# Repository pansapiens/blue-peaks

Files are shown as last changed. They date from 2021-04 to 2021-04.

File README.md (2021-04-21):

# Blue Peaks

A low-cost remix of [Mutable instrument's Peaks](https://mutable-instruments.net/modules/peaks/) and [Matias Levy Alfie's $peaks](https://github.com/matias-levy/peaks).

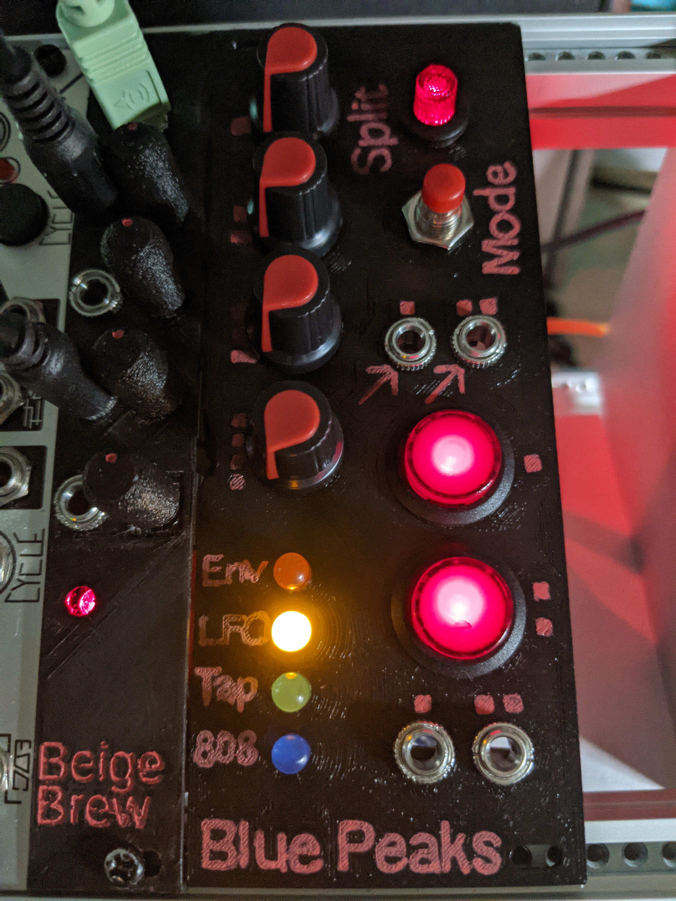
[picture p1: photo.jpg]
Photo of the finished build


## Description
This is a 'skiff friendly' remix of Matias Levy Alfie's awesome [$peaks](https://github.com/matias-levy/peaks) module (which in turn is based on [Mutable instrument's Peaks](https://mutable-instruments.net/modules/peaks/)), with the PCB redesigned with a depth of 50 cm. See [Matias repo](https://github.com/matias-levy/peaks) for details on how he redesigned the module to use a Blue Pill without an external DAC !

It also includes versions of the original Peaks and the Dead Man's Catch firmwares trimmed to fit on a Blue Pill (STM32F103C8T6 dev board) with only 64k of flash. You can use this firmware with Matias' $peaks if you prefer to make that PCB.

Like Matias' original remix, the project is designed to use a single sided home-etched PCB with ~~a couple of~~ far too many jumper wires.
## Firmwares
There's the option to flash one of two firmwares that where ported. The original Mutable Instruments one is in the `firmware/peaks` directory. The [Mutated Mutables Dead Man's Catch](https://github.com/timchurches/Mutated-Mutables/tree/master/peaks) is in the `firmware/peaks2`.

By default the "Number Station" Easter egg in the firmware is disabled to allow it to fit on a Blue Pill with 64k of flash. If you have 128k of flash it can be enabled in the `makefile` (see below).

Compiled binaries and HEX files are provided for both under `firmware/build`.

## Matias changes from Peaks
* Added a driver for the PWM DAC running at **14 bit depth, 48Khz sampling rate.** (File in firmware/peaks/drivers/pwm_dac.h)
* Activated the clock for the TIM4 in firmware/peaks/drivers/system.cc
* **Bypassed the bootloader:** This was done as to simplify the code, it does not interfere with the calibration functionality of the module.
* Redesigned the output portion of the hardware to accommodate to the PWM levels.

## Further changes from $peaks
* Modified board layout to be 'skiff friendly' (PCB is 50mm deep, 110 mm high)
* Disabled the "Number Station" Easter egg by default, to fit in 64k flash.
* Tweaked to use default KiCad footprints, less vertically mounted resistors, use 9mm horizontal Alpha-style pots (eg RD901F / RK09)
* Use 5.1V Zener diodes rather than 3.6V.
* Tweaked tracks to work better for my own PCB production method (pen plotter + etching)

## Build guide

Mine looked like this. You are on your own ... have fun !

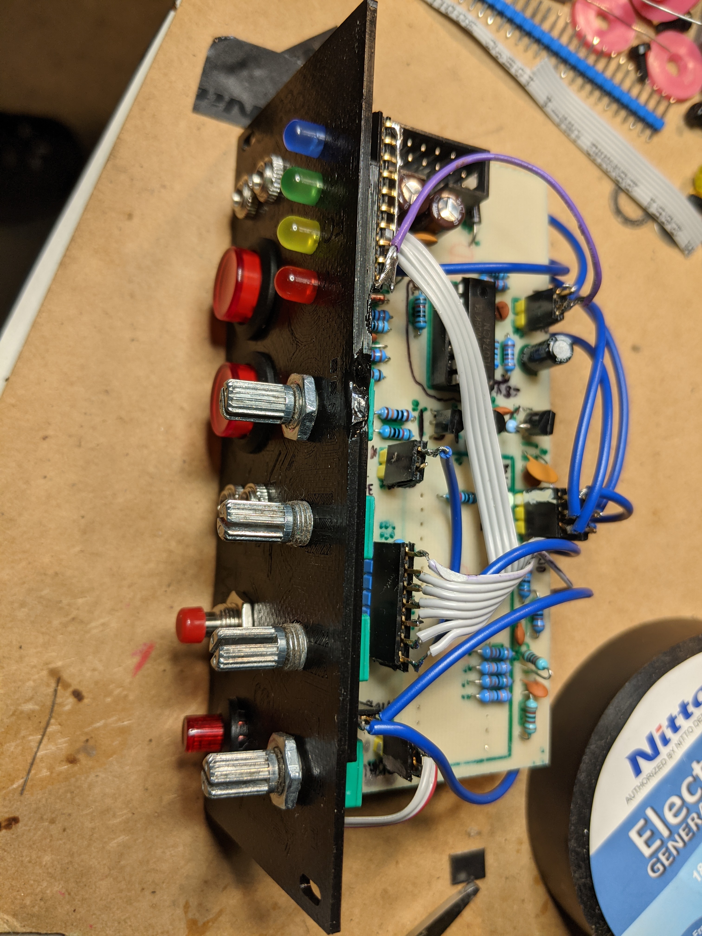
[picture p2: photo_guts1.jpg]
PCB 'front'


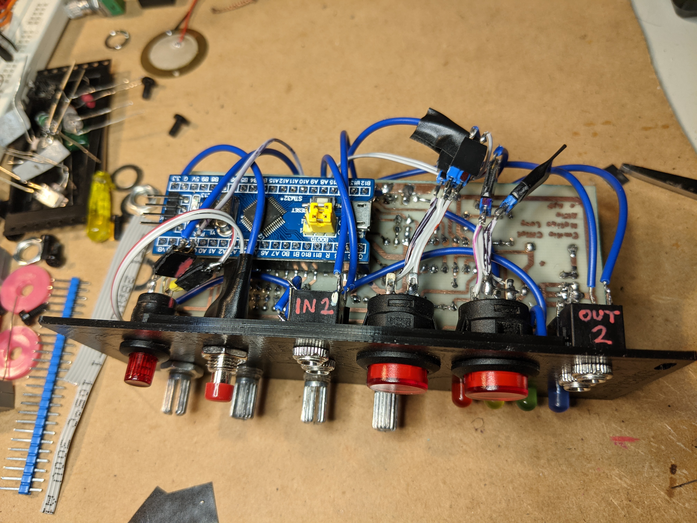
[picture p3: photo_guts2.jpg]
PCB 'back'


Yup, it's a rat's nest. I would love to find the time to redesign further to limit the number of jumper wires.

**WARNING WARNING WARNING** - I found some weirdness in the orientation / side of PCB that some components needed to be soldered in this design. By the time I discovered it I'd already made the PCBs so I worked around it. I ended up soldering the Blue Pill on the opposite side to the other components (awkward), and flipping the transistors, voltage regulator, TL074 and power socket 180 degrees to ensure the pinouts correctly aligned with the approriate tracks / schematic. So fair warning - be paranoid about component orientation and don't blindly trust the silkscreen layer. Visually check that the pins you are soldering make sense with the tracks they connect to (eg wide ground trace). If you don't check carefully as you go, you'd better enjoy desoldering components ....

## Flashing and development
Build with:
```
cd firmware
make -f peaks/makefile
make -f peaks/makefile bin
```

You'll need Python 2.x and `numpy`, as well as a typical Linux build environment for ARM cross-compilation 
(eg On Ubuntu 20.04, do `sudo apt install gcc-arm* build-essential` and set `TOOLCHAIN_PATH = /usr/` in `firmware/peaks/makefile`).

If you happen to have a Blue Pill with 128k of flash, you can enable the "Number Station" Easter egg by uncommenting the `NUMBER_STATION` variable in `firmware/peaks/makefile`.

To make it easier there are pre-compiled binaries and .HEX files in `firmware/build`, this can be flashed directly to the bluepill using [STM32CubeProgrammer](https://www.st.com/en/development-tools/stm32cubeprog.html).

Another option is to install the [mutable-dev-environment](https://github.com/pichenettes/mutable-dev-environment) and replace the peaks folder with the one inside /firmware, then executing

    make -f peaks/makefile upload_serial

We use this command because the bootloader is bypassed.

## Thanks
Many thanks Emilie Gillet for open-sourcing her work which is a constant inspiration for many musicians and makers, and encourage everyone interested in this project to checkout the [Mutable instrument's Forum](https://forum.mutable-instruments.net/) in which Emilie is a very active member.

## TODO, IDEAS

- Resolve issues with flipped components / which side to solder / front vs. back traces.
  - To get correct connections I needed to solder the Blue Pill pin header sockets on the 'wrong' side of the PCB 
    (the opposite side to other components - quite awkward on a single sided PCB),
    and rotate the TL074, transistors and voltage regulator 180 degrees to allow them to be correctly soldered to 
    the 'right' side of the board.
    
- Change some GPIOs in the firmware to make PCB layout easier/cleaner.
- Use a 3.3V supply to power the Blue Pill (eg via LD1117AV33 / LM1117-3.3) rather than 5V - apparently the 5V to 3.3V regulator on Blue Pill boards can't handle more the 100mA, so it's safer to supply 3.3V directly.
- For matching R14/R16 to the Zener reference voltage, 21k and 14k resistors are tricky to find. Either use a 20+1k / 13+1k (or maybe use a resistor + 1k or 2k trimpot to allow manual calibration ?)
- Create a two PCB design with pots/jacks/switches soldered on front board. The single board version is a mess of wires.
- Add CV control for each of the four pots !

While I don't plan to tackle any of these changes within the foreable future, I figured it was worth documenting.

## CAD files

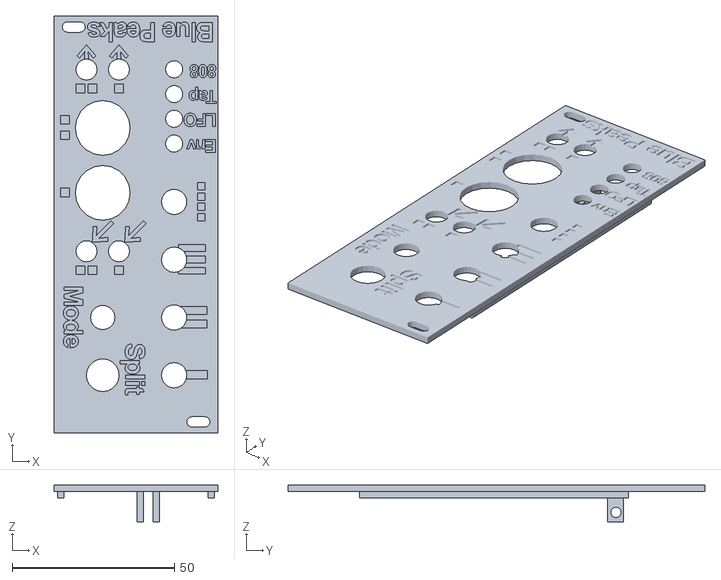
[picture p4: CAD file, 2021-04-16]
frontpanel/stl/EurorackPanel_10HP_Blue_Peaks.stl
50.5 x 128.5 x 11.3

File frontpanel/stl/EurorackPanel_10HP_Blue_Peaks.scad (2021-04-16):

// In this design, the illuminated buttons are inserted from the front of the panel and are held without nuts.
// This means the fit of the holes needs to be fairly snug. If you have different illuminated momentary buttons
// you'll need to tweak the radii in ledMomRad, bbRadius and momRad.

// Large momentary trigger buttons are Shin Chin (SCI) R13-523A (R13-523A-05-BR, Mouser code: 112-R13-523A-05-BR).
// Split/twin momentary button is Shin Chin (SCI) R13-548A (R13-548AL-05-BRR, Mouser code: 112-R13-548AL-BRR)

// Mode toggle momentary button has a ~6mm diameter metal thread with nut (similar to Philips PBS-110, or maybe Shin Chin R13-24A).
// LEDs are standard 5mm diameter LEDs.
// Sockets are standard threaded 3.5mm mono jacks with nuts.
// Pots are Alps-style (RK09) metal threaded with nuts.

// TODO: Mounting bracket for M3 screw is too weak, needs be thicker at the base where it joins the panel

$fn = 24;

panelThickness = 2;
panelHp = 10;  // 10HP is actually 50.50 based on http://www.doepfer.de/a100_man/a100m_e.htm
holeCount = 2;
holeWidth = 7.08; //If you want wider holes for easier mounting. Otherwise set to any number lower than mountHoleDiameter. Can be passed in as parameter to eurorackPanel()

threeUHeight = 133.35; //overall 3u height
panelOuterHeight = 128.5;
panelInnerHeight = 110; //rail clearance = ~11.675mm, top and bottom
railHeight = (threeUHeight-panelOuterHeight)/2;
mountSurfaceHeight = (panelOuterHeight-panelInnerHeight-railHeight*2)/2;

// Start and end coordinates of PCB top/bottom edges
innerStartY = 0 + ((panelOuterHeight - panelInnerHeight)/2);
innerEndY = panelOuterHeight - ((panelOuterHeight - panelInnerHeight)/2);

echo("mountSurfaceHeight", mountSurfaceHeight);

hp=5.08;
// This is a 'naive' width - based on based on http://www.doepfer.de/a100_man/a100m_e.htm,
// Doepfer panel widths have some tolerances/rounding in values.
// 
// panelWidth=panelHp*hp;
panelWidth=50.50; // 10HP

// R13-548A
ledMomRad = (8.5 + 1.6)/2;  // snug + tolerance/slope (snap fit)   // (8.5 + 1)/2 too tight // (10+1)/2 far too loose // (8.5 + 2)/2 slightly loose
momRad = (6.5 + 1)/2;  // snug + tolerance, secured with nut      // good fit

// R13-523A - these are snap fit buttons, so we should get a snug fit even with a bit of slop
bbRadius=(15.5 + 1.4)/2; // snug + tolerance/slop  //(15.5 + 1)/2 too tight // (17.5+1)/2 far too loose  // (15.5 + 2)/2 a bit loose

// plastic 9mm Alpha-style RK09 vertical pots, snug fit, no nut
// potRadius==6.45/2;

// metal alpha pot (knurled) - loose fit for attaching with nut
potRadius=7.8/2;  // 7/2 too tight  // 8.2/2 a bit loose

potHoleSpacing=17.8;

// snug fit 3.5mm jack, secured with nut
socketRadius=6.5/2;  // good fit

ledHoleWidth = 5.3; // 5.3 tight fit, won't fall out // 5.1 too tight  // 5.5 fits but slightly loose

mountHoleDiameter = 3.2;
mountHoleRad = mountHoleDiameter/2;
hwCubeWidth = holeWidth-mountHoleDiameter;
mountholeXOffset=1;

offsetToMountHoleCenterY = mountSurfaceHeight/2;
offsetToMountHoleCenterX = hp - hwCubeWidth/2; // 1 hp from side to center of hole

// reinforcementDepth=2.8;  // needs to be short enough to clear base of potentiometer
reinforcementDepth=2;  // MIDI sockets need a fair amount of force to insert, so we need extra reinforcment

m3_screwhole_d=2.95; // should engage screw thread

echo(offsetToMountHoleCenterY);
echo(offsetToMountHoleCenterX);

// TODO: This is too weak, needs be thicker at the base where it joins the panel
module mountingBracket() {
    xOffset=28;
    yOffset=panelOuterHeight-30;
    bracketLength=9.3;
    bracketThickness=2;
    pcbThickness=2;
    holeOffset=6.4;  // 5.6 too short
    holeR=(m3_screwhole_d+0.2)/2;
    

    difference() {
        union()
        {
            translate([xOffset-bracketThickness-0.5, yOffset, -bracketLength]) {
                cube([bracketThickness, m3_screwhole_d+2, bracketLength]);
            }
            translate([xOffset+bracketThickness+0.5, yOffset, -bracketLength]) {
                cube([bracketThickness, m3_screwhole_d+2, bracketLength]);
            }
        }
        translate([xOffset+1, yOffset+holeR+1, -holeOffset]) {
            rotate([90,0,90]) cylinder(r=holeR, h=(bracketThickness*2)+pcbThickness+2, center=true, $fn=20);
        }
    }
}

module momButtonHoles() {    
    union()
    {
        translate([15, (potHoleSpacing*1), -reinforcementDepth-2]) {
            cylinder(r=ledMomRad, h=reinforcementDepth+5, $fn=20);
        }
        translate([15, (potHoleSpacing*2), -reinforcementDepth-2]) {
            cylinder(r=momRad, h=reinforcementDepth+5, $fn=20);
        }
    }
}

module bigButtonHoles() {
    union()
    {
        translate([15, 74, -reinforcementDepth-2]) {
            cylinder(r=bbRadius, h=reinforcementDepth+5, $fn=20);
        }
        translate([15, 94, -reinforcementDepth-2]) {
            cylinder(r=bbRadius, h=reinforcementDepth+5, $fn=20);
        }
    }
}

module socketHoles(socketRadius) {
    
    union()
    {
        translate([20-10, 74-18, -reinforcementDepth-2]) {
            cylinder(r=socketRadius, h=reinforcementDepth+5, $fn=20);
        }
        translate([20, 74-18, -reinforcementDepth-2]) {
            cylinder(r=socketRadius, h=reinforcementDepth+5, $fn=20);
        }
        translate([20-10, 112, -reinforcementDepth-2]) {
            cylinder(r=socketRadius, h=reinforcementDepth+5, $fn=20);
        }
        translate([20, 112, -reinforcementDepth-2]) {
            cylinder(r=socketRadius, h=reinforcementDepth+5, $fn=20);
        }
    }
}

// specific set of 2HP central 9mm vertical pot holes holes
module potHoles(pw, potRadius) {
    xOff=pw-13.5;
    
    union()
    {
        translate([xOff, (potHoleSpacing*1), -reinforcementDepth-2]) {
            cylinder(r=potRadius, h=reinforcementDepth+5, $fn=20);
        }
        translate([xOff, (potHoleSpacing*2), -reinforcementDepth-2]) { 
            cylinder(r=potRadius, h=reinforcementDepth+5, $fn=20);
        }
        translate([xOff, (potHoleSpacing*3), -reinforcementDepth-2]) { 
            cylinder(r=potRadius, h=reinforcementDepth+5, $fn=20);
        }
        translate([xOff, (potHoleSpacing*4), -reinforcementDepth-2]) {
            cylinder(r=potRadius, h=reinforcementDepth+5, $fn=20);
        }
    }
}

module ledHoles(pw) {
    xOff=pw-13.5;
    startY=89.2;
    union()
    {
        translate([xOff, startY, -reinforcementDepth-2]) {
            cylinder(r=ledHoleWidth/2, h=reinforcementDepth+5, $fn=20);
        }
        translate([xOff, startY + (3*2.54), -reinforcementDepth-2]) {
            cylinder(r=ledHoleWidth/2, h=reinforcementDepth+5, $fn=20);
        }
        translate([xOff, startY + (6*2.54), -reinforcementDepth-2]) {
            cylinder(r=ledHoleWidth/2, h=reinforcementDepth+5, $fn=20);
        }
        translate([xOff, startY + (9*2.54), -reinforcementDepth-2]) {
            cylinder(r=ledHoleWidth/2, h=reinforcementDepth+5, $fn=20);
        }
    }
}

module reinforcement() {
    union() {
        translate([panelThickness/2,                  22, -reinforcementDepth]) cube([panelThickness,panelInnerHeight/3,reinforcementDepth]);
        translate([panelWidth-(panelThickness*1.5), 22, -reinforcementDepth]) cube([panelThickness,panelInnerHeight/3,reinforcementDepth]);
        translate([panelThickness/2,                  50, -reinforcementDepth]) cube([panelThickness,panelInnerHeight/2,reinforcementDepth]);
        translate([panelWidth-(panelThickness*1.5), 50, -reinforcementDepth]) cube([panelThickness,panelInnerHeight/2,reinforcementDepth]);
        
        // zrail lock
        // This is hard to get in the right position and doesn't add much rigidity of guidance. Usually not worth it.
        /*
        zrailLockWidth=1.5;
        zrailLockInset=9.3;
        translate([0, zrailLockInset, -reinforcementDepth]) cube([panelHp*hp, zrailLockWidth, reinforcementDepth]);
        translate([0, panelOuterHeight-zrailLockInset-zrailLockWidth, -reinforcementDepth]) cube([panelHp*hp, zrailLockWidth, reinforcementDepth]);
        */
    }
}
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

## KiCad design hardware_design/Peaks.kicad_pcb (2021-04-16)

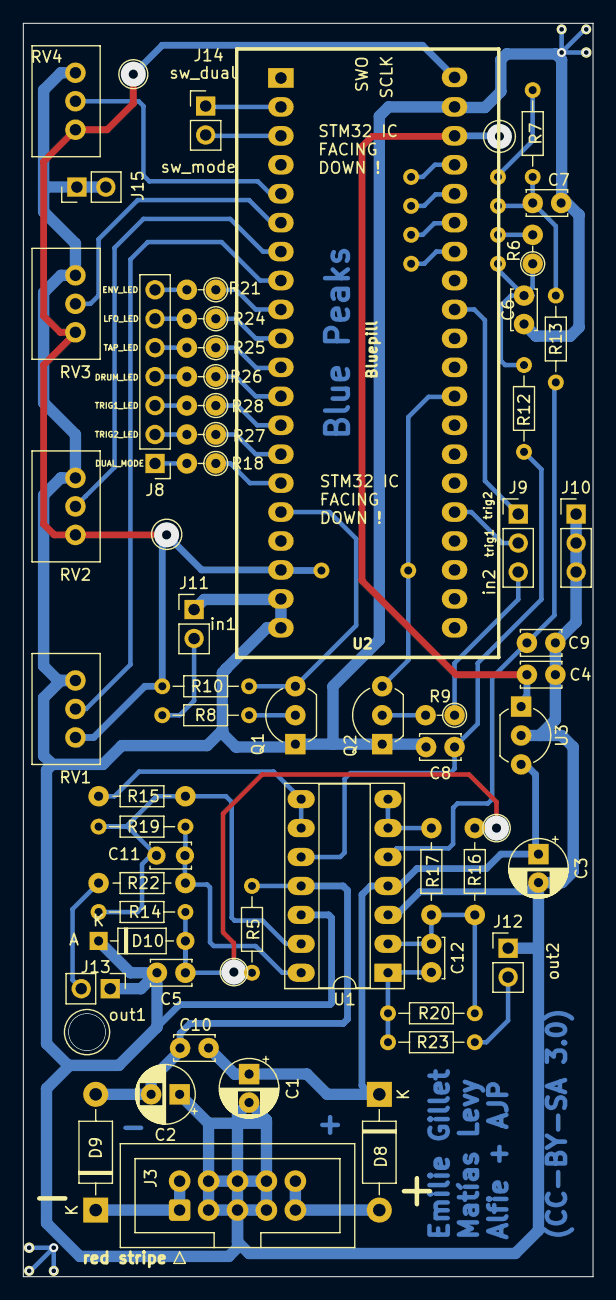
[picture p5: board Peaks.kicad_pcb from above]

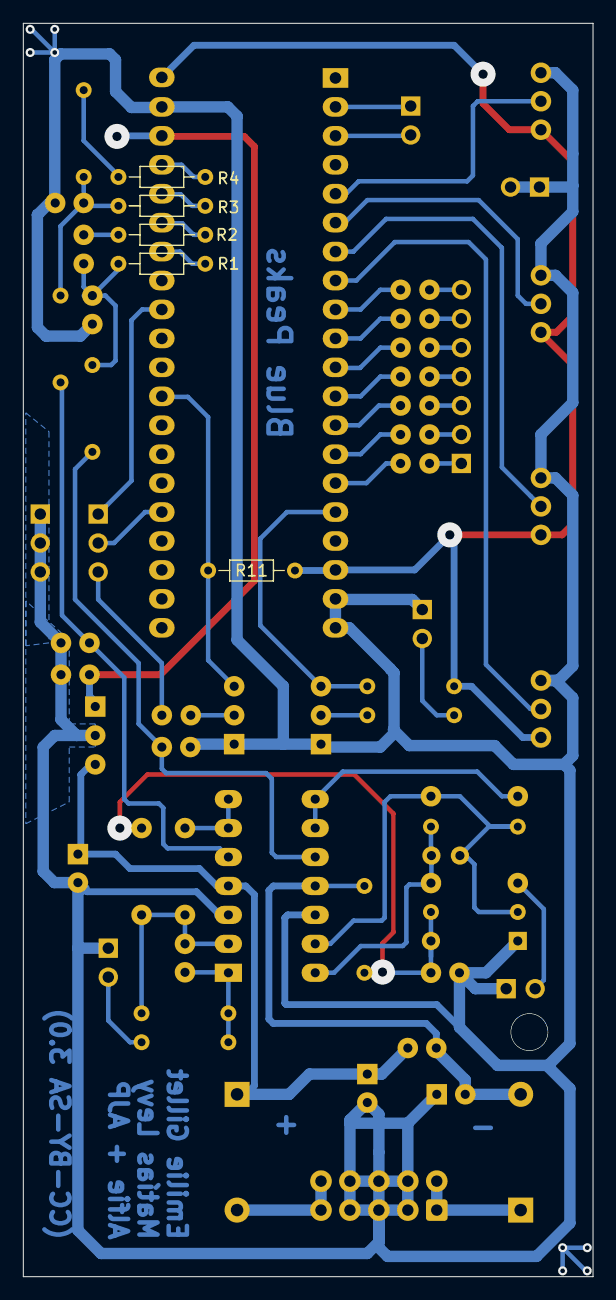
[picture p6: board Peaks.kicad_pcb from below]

Board: 2 copper layers, 50.0 x 110.0 mm, 61 parts (5 on the bottom side), 54 nets.

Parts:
C1, C2: 10u; CP_Radial_D5.0mm_P2.50mm_Large_Pads
C3: 0,33u; CP_Radial_D5.0mm_P2.50mm_Large_Pads
C4, C5, C10: 100n; C_Disc_D3.4mm_W2.1mm_P2.50mm_Large_Pads
C6, C7, C8, C9: 4.7n; C_Disc_D3.4mm_W2.1mm_P2.50mm_Large_Pads
C11: 150pf; C_Disc_D3.4mm_W2.1mm_P2.50mm
C12: 150pf; C_Disc_D3.4mm_W2.1mm_P2.50mm_Large_Pads
D8, D9: 1N5817; D_DO-41_SOD81_P10.16mm_Horizontal
D10: 5.1; D_DO-35_SOD27_P7.62mm_Horizontal
J3: Eurorack Power; IDC-Header_2x05_P2.54mm_Vertical_Large_Pads
J8: Conn_01x07; PinHeader_1x07_P2.54mm_Vertical
J9, J10: PinHeader_1x03_P2.54mm_Vertical
J11, J12, J13, J14, J15: PinHeader_1x02_P2.54mm_Vertical
Q1, Q2: 2N3904; TO-92_Inline_Wide_Large_Pads
R1, R3, R12, R13: 1k5; R_Axial_DIN0204_L3.6mm_D1.6mm_P7.62mm_Horizontal
R2, R4: 180k; R_Axial_DIN0204_L3.6mm_D1.6mm_P7.62mm_Horizontal
R5, R10, R11: 10k; R_Axial_DIN0204_L3.6mm_D1.6mm_P7.62mm_Horizontal
R6: 12k; R_Axial_DIN0204_L3.6mm_D1.6mm_P2.54mm_Vertical_Large_Pads
R7: 12k; R_Axial_DIN0204_L3.6mm_D1.6mm_P7.62mm_Horizontal
R8: 100k; R_Axial_DIN0204_L3.6mm_D1.6mm_P7.62mm_Horizontal
R9: 100k; R_Axial_DIN0204_L3.6mm_D1.6mm_P2.54mm_Vertical_Large_Pads
R14: 21k; R_Axial_DIN0204_L3.6mm_D1.6mm_P7.62mm_Horizontal
R15, R17: 6k8; R_Axial_DIN0204_L3.6mm_D1.6mm_P7.62mm_Horizontal_Large_Pads
R16: 21k; R_Axial_DIN0204_L3.6mm_D1.6mm_P7.62mm_Horizontal_Large_Pads
R18, R21, R24, R25, R26, R27, R28: 2k; R_Axial_DIN0204_L3.6mm_D1.6mm_P2.54mm_Vertical_Large_Pads
R19, R20: 33k; R_Axial_DIN0204_L3.6mm_D1.6mm_P7.62mm_Horizontal
R22: 1k; R_Axial_DIN0204_L3.6mm_D1.6mm_P7.62mm_Horizontal_Large_Pads
R23: 1k; R_Axial_DIN0204_L3.6mm_D1.6mm_P7.62mm_Horizontal
RV1, RV2, RV3, RV4: B10k; Potentiometer_Alps_RK097_Single_Horizontal
U1: TL074; DIP-14_W7.62mm_Socket_LongPads
U2: Bluepill; BluePill_STM32F103C
U3: 78l05; TO-92_Inline_Wide_Large_Pads

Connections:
3.3V: R10.1, R11.1, RV1.3, RV2.3, RV3.3, RV4.3, U2.18, U2.40
+5V: C4.1, U2.38, U3.1
+12V: C1.1, C3.1, C10.1, D8.1, U1.4, U3.3
-12V: C2.2, C10.2, D9.2, R5.2, U1.11
/CH1_PWM1: R1.2, U2.34
/CH1_PWM2: R2.2, U2.35
/CH2_PWM1: R3.2, U2.36
/CH2_PWM2: R4.2, U2.37
/LED1: R18.1, U2.15
/LED2: R21.1, U2.9
/LED3: R24.1, U2.10
/LED4: R25.1, U2.11
/LED5: R26.1, U2.12
/LED_SALIDA_1: R27.1, U2.14
/LED_SALIDA_2: R28.1, U2.13
/POT_1: RV1.2, U2.8
/POT_2: RV2.2, U2.7
/POT_3: RV3.2, U2.6
/POT_4: RV4.2, U2.5
/REF_-3.6: C5.1, D10.2, R5.1, R14.2, R16.2
/SW_DUAL: J14.1, U2.2
/SW_MODE: J14.2, U2.3
/SW_TRIG1: J9.2, U2.25
/SW_TRIG2: J9.1, U2.32
/TRIG_1: Q1.3, R10.2, U2.16
/TRIG_2: Q2.3, R11.2, U2.29
GND: C1.2, C2.1, C3.2, C4.2, C5.2, C6.2, C7.2, C8.2, C9.2, D10.1, J3.3, J3.4, J3.5, J3.6, J3.7, J3.8, J10.1, J10.2, J10.3, J11.1, J12.1, J13.1, J15.1, J15.2, Q1.1, Q2.1, RV1.1, RV2.1, RV3.1, RV4.1, U1.3, U1.12, U2.19, U2.20, U2.39, U3.2
unnamed: C6.1, R1.1, R6.1, R12.2
unnamed: C7.1, R3.1, R7.1, R13.2
unnamed: C8.1, R12.1, U1.10
unnamed: C9.1, R13.1, U1.5
unnamed: C11.1, R14.1, R15.1, R19.2, U1.13
unnamed: C11.2, R19.1, R22.2, U1.14
unnamed: C12.1, R16.1, R17.1, R20.2, U1.2
unnamed: C12.2, R20.1, R23.2, U1.1
unnamed: D8.2, J3.9, J3.10
unnamed: D9.1, J3.1, J3.2
unnamed: Q1.2, R8.2
unnamed: Q2.2, R9.2
unnamed: R2.1, R6.2
unnamed: R4.1, R7.2
unnamed: R15.2, U1.8, U1.9
unnamed: R17.2, U1.6, U1.7
TO_D1: J8.1, R18.2
TO_D2: J8.7, R21.2
TO_D3: J8.6, R24.2
TO_D4: J8.5, R25.2
TO_D5: J8.4, R26.2
TO_D6: J8.2, R27.2
TO_D7: J8.3, R28.2
TO_IN1: J11.2, R8.1
TO_IN2: J9.3, R9.1
TO_OUT1: J13.2, R22.1
TO_OUT2: J12.2, R23.1

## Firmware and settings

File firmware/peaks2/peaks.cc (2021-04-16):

// Copyright 2014 Emilie Gillet.
//
// Author: Emilie Gillet (emilie.o.gillet@gmail.com)
//
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
// See http://creativecommons.org/licenses/MIT/ for more information.

#include <stm32f10x_conf.h>

#include "stmlib/utils/dsp.h"
#include "stmlib/utils/ring_buffer.h"
#include "stmlib/system/system_clock.h"

#include "peaks2/drivers/pwm_dac.h"
#include "peaks2/drivers/debug_pin.h"
#include "peaks2/drivers/gate_input.h"
#include "peaks2/drivers/system.h"

#include "peaks2/calibration_data.h"
#include "peaks2/io_buffer.h"
#include "peaks2/processors.h"
#include "peaks2/ui.h"

using namespace peaks;
using namespace std;
using namespace stmlib;

Adc adc;
CalibrationData calibration_data;
PWMDac pwm_dac;
GateInput gate_input;
IOBuffer io_buffer;
Leds leds;
Switches switches;
System sys;
Ui ui;

extern "C" {

void HardFault_Handler(void) { while (1); }
void MemManage_Handler(void) { while (1); }
void BusFault_Handler(void) { while (1); }
void UsageFault_Handler(void) { while (1); }
void NMI_Handler(void) { }
void SVC_Handler(void) { }
void DebugMon_Handler(void) { }
void PendSV_Handler(void) { }

}

extern "C" {

uint16_t counter = 0;

void SysTick_Handler() {
  ui.Poll();
}

GateFlags gate_flags[2];

void TIM1_UP_IRQHandler(void) {
  // DAC refresh at 48kHz
  if (!(TIM1->SR & TIM_IT_Update)) {
    return;
  }
  TIM1->SR = (uint16_t)~TIM_IT_Update;

  bool wrote_both_channels = pwm_dac.Update();
  if (!wrote_both_channels) {
    return;
  }

  uint32_t external_gate_inputs = gate_input.Read();
  uint32_t buttons = ui.ReadPanelGateState();
  uint32_t gate_inputs = external_gate_inputs | buttons;

  IOBuffer::Slice slice = io_buffer.NextSlice(1);
  for (size_t i = 0; i < kNumChannels; ++i) {
    gate_flags[i] = ExtractGateFlags(
        gate_flags[i],
        gate_inputs & (1 << i));
    pwm_dac.Write(i, slice.block->output[i][slice.frame_index]);
  }

  // A hack to make channel 1 aware of what's going on in channel 2. Used to
  // reset the sequencer.
  slice.block->input[0][slice.frame_index] = gate_flags[0] \
      | (gate_flags[1] << 4) \
      | (buttons & 1 ? GATE_FLAG_FROM_BUTTON : 0);

  slice.block->input[1][slice.frame_index] = gate_flags[1] \
      | (buttons & 2 ? GATE_FLAG_FROM_BUTTON : 0);
}

}

int16_t output_buffer[kBlockSize];

void Process(IOBuffer::Block* block, size_t size) {
  // DebugPin::High();
  ui.PollPots();
  for (size_t i = 0; i < kNumChannels; ++i) {
    if (ui.calibrating()) {
      fill(&output_buffer[0], &output_buffer[size], 0);
    } else {
      processors[i].Process(block->input[i], output_buffer, size);
    }
    ui.set_led_brightness(i, output_buffer[0]);
    for (size_t j = 0; j < size; ++j) {
      block->output[i][j] = calibration_data.DacCode(i, output_buffer[j]);
    }
  }
  // DebugPin::Low();
}

void Init() {
  sys.Init(F_CPU / 96000 - 1, false);

  system_clock.Init();
  gate_input.Init();
  io_buffer.Init();
  pwm_dac.Init();

  calibration_data.Init();
  processors[0].Init(0);
  processors[1].Init(1);
  ui.Init(&calibration_data);

  // DebugPin::Init();

  sys.StartTimers();
}

int main(void) {
  Init();
  while (1) {
    ui.DoEvents();
    io_buffer.Process(&Process);
  }
}

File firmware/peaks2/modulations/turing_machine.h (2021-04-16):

// Copyright 2013 Emilie Gillet, 2015 Tim Churches
//
// Author: Emilie Gillet (emilie.o.gillet@gmail.com)
// Modifications: Tim Churches (tim.churches@gmail.com)
// Modifications may be determined by examining the differences between the last commit
// by Emilie Gillet (pichenettes) and the HEAD commit at
// https://github.com/timchurches/Mutated-Mutables/tree/master/peaks
//
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
// See http://creativecommons.org/licenses/MIT/ for more information.
//
// -----------------------------------------------------------------------------
//
// Mini sequencer.

#ifndef PEAKS_MODULATIONS_TURING_MACHINE_H_
#define PEAKS_MODULATIONS_TURING_MACHINE_H_

#include "stmlib/stmlib.h"

#include <algorithm>

#include "peaks2/gate_processor.h"

#include "stmlib/utils/dsp.h"
#include "stmlib/utils/random.h"

namespace peaks {

class TuringMachine {
 public:
  TuringMachine() { }
  ~TuringMachine() { }

  void Init() {
    turing_length_ = 8;
    turing_prob_ = 0;
    turing_divider_ = 1;
    turing_span_ = 0;
    turing_shift_register_ = stmlib::Random::GetWord();
    turing_lsb_ = turing_shift_register_ & static_cast<uint32_t>(1);
    turing_remainder_lsb_ = false;
    turing_value_ = 0;
    turing_div_counter_ = 0;
  }

  inline void set_turing_length(uint16_t value) {
    if (value < 9362) {
      turing_length_ = 8;
    } else if (value < 18724) {
      turing_length_ = 12;
    } else if (value < 28086) {
      turing_length_ = 16;
    } else if (value < 37449) {
      turing_length_ = 20;
    } else if (value < 46822) {
      turing_length_ = 24;
    } else if (value < 56173) {
      turing_length_ = 28;
    } else {
      turing_length_ = 32;
    }
  }

  inline void set_turing_prob(uint16_t value) {
    if (value > 63487) {
      turing_prob_ = 65535;
    } else {
      turing_prob_ = value >> 3 ;
    }
  }

  inline void set_turing_divider(uint16_t value) {
    turing_divider_ = (value >> 13) + 1;
  }

  inline void set_turing_span(uint16_t value) {
    turing_span_ = value;
  }

  void Configure(uint16_t* parameter, ControlMode control_mode) {
    if (control_mode == CONTROL_MODE_HALF) {
      set_turing_prob(parameter[0]);
      set_turing_span(parameter[1]);
    } else {
      set_turing_prob(parameter[0]);
      set_turing_span(parameter[1]);
      set_turing_length(parameter[2]);
      set_turing_divider(parameter[3]);
    }
  }

  void Process(const GateFlags* gate_flags, int16_t* out, size_t size) {
    while (size--) {
      GateFlags gate_flag = *gate_flags++;

      if (gate_flag & GATE_FLAG_RISING) {
        ++turing_div_counter_;
        if (turing_div_counter_ >= turing_divider_) {
          turing_div_counter_ = 0 ;
          // read the LSB
          turing_lsb_ = turing_shift_register_ & static_cast<uint32_t>(1);
          // read the LSB in the remainder of the shift register
          if (turing_length_ < 32) {
             turing_remainder_lsb_ = turing_shift_register_ & (static_cast<uint32_t>(1) << turing_length_);
          }
          // rotate the shift register
          turing_shift_register_ = turing_shift_register_ >> 1;
          // add back the LSB into the MSB postion
          if (turing_lsb_) {
             turing_shift_register_ |= (static_cast<uint32_t>(1) << (turing_length_ - 1));
          } else {
             turing_shift_register_ &= (~(static_cast<uint32_t>(1) << (turing_length_ - 1)));
          }
          // add back the LSB to the remainder of the shift register
          if (turing_length_ < 32) {
             if (turing_remainder_lsb_) {
                turing_shift_register_ |= (static_cast<uint32_t>(1) << 31);
             } else {
                turing_shift_register_ &= (~(static_cast<uint32_t>(1) << 31));
             }
          }
          // Decide whether to re-initialise and skip the rest, or not
          if (false) {
              turing_shift_register_ = stmlib::Random::GetWord();
              turing_lsb_ = turing_shift_register_ & static_cast<uint32_t>(1);
          } else {
  			// read the LSB
  			turing_lsb_ = turing_shift_register_ & static_cast<uint32_t>(1);
  			// read the LSB in the remainder of the shift register
  			if (turing_length_ < 32) {
  			   turing_remainder_lsb_ = turing_shift_register_ & (static_cast<uint32_t>(1) << turing_length_);
  			}
  			// rotate the shift register
  			turing_shift_register_ = turing_shift_register_ >> 1;
  			// add back the LSB into the MSB postion
  			if (turing_lsb_) {
  			   turing_shift_register_ |= (static_cast<uint32_t>(1) << (turing_length_ - 1));
  			} else {
  			   turing_shift_register_ &= (~(static_cast<uint32_t>(1) << (turing_length_ - 1)));
  			}
  			// add back the LSB to the remainder of the shift register
  			if (turing_length_ < 32) {
  			   if (turing_remainder_lsb_) {
  				  turing_shift_register_ |= (static_cast<uint32_t>(1) << 31);
  			   } else {
  				  turing_shift_register_ &= (~(static_cast<uint32_t>(1) << 31));
  			   }
  			}
  			// decide whether to flip the LSB
  			uint16_t random = stmlib::Random::GetSample();
  			if (random < turing_prob_) {
  			   // bit-flip the LSB
  			   turing_shift_register_ = turing_shift_register_ ^ static_cast<uint32_t>(1) ;
  	        }
  	    }
          turing_byte_ = turing_shift_register_ & static_cast<uint32_t>(0xFF);
          turing_value_ = (turing_byte_ * (turing_span_ >> 10)); // was 9
        }
      }
      *out++ = turing_value_;
    }
  }

 private:
  uint16_t turing_length_;
  uint16_t turing_prob_;
  uint16_t turing_divider_;
  uint16_t turing_span_;
  uint32_t turing_shift_register_;
  bool turing_lsb_;
  bool turing_remainder_lsb_;
  uint32_t turing_byte_;
  int16_t turing_value_;
  uint8_t turing_div_counter_;

  DISALLOW_COPY_AND_ASSIGN(TuringMachine);
};

}  // namespace peaks

#endif  // PEAKS_MODULATIONS_TURING_MACHINE_H_

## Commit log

2021-04-12 Make Number Station optional for 64k flash boards.
    New builds for 64k Blue Pills.
    README notes about changes.
2021-04-16 Remixed hardware.
    Skiff friendly (50cm depth) PCB.
    Revert to using more standard KiCad footprints.
    Use a 5.1V Zener diode for PWM scaling.
    [Peaks.kicad_pcb, Peaks.sch]
2021-04-16 Add 3D printable front panel design.
    [EurorackPanel_10HP_Blue_Peaks.scad, EurorackPanel_10HP_Blue_Peaks.stl]
2021-04-16 Remove original front panel design.
    The old front panel template probably doesn't fit the new PCB design here, so I've removed it.
2021-05-02 Compilation option to reverse pot order.
    Seems the current design has the pots wired in reverse order (or I just did it wrong). The REVERSE_POT_ORDER option in the makefile allows this to be corrected in the firmware).

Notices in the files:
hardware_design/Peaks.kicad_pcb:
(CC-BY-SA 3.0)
